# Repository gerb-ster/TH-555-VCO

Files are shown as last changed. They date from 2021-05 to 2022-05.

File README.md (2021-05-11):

# Thomas Henry 555 VCO

The famous VCO module by Thomas Henry based on the 555 timer IC. This was the first module I ever designed a PCB for, which, in hindsight, was not the smartest move. It took me quit a while to get it bug-free, but now that it works, I love it! Over the years I read a lot of articles and booklets by Thomas Henry and if you’re into this synth diy stuff, I highly recommend checking out him and his work. If you want to build/buy one yourself, there is also an excellent version out there by a guy named Fonitronik, there is a link below.

## Status: Finished

- done: first schematic & board design
- done: breadboard and test
- done: design frontpanel
- done: order PCB and build prototype

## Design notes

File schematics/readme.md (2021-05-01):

## Disclaimer

The files/schematics found in this folder are made with Eagle CAD v9.6.2.

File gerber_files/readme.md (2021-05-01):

## Gerber Files

This folder contains all Gerber files.

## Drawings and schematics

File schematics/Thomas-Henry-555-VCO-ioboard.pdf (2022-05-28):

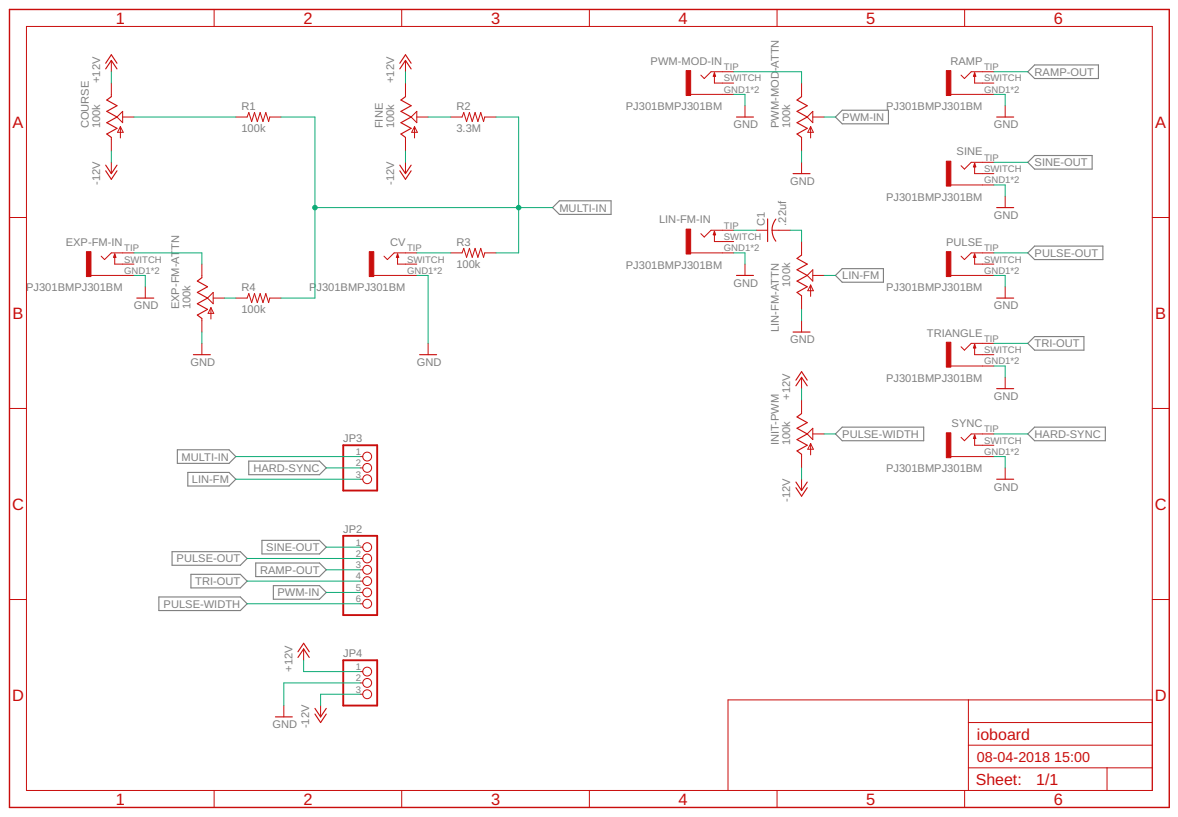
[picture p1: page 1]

SWITCH GND1*2 PWM-MOD-IN

SWITCH GND1*2 LIN-FM-IN

SWITCH GND1*2 EXP-FM-IN

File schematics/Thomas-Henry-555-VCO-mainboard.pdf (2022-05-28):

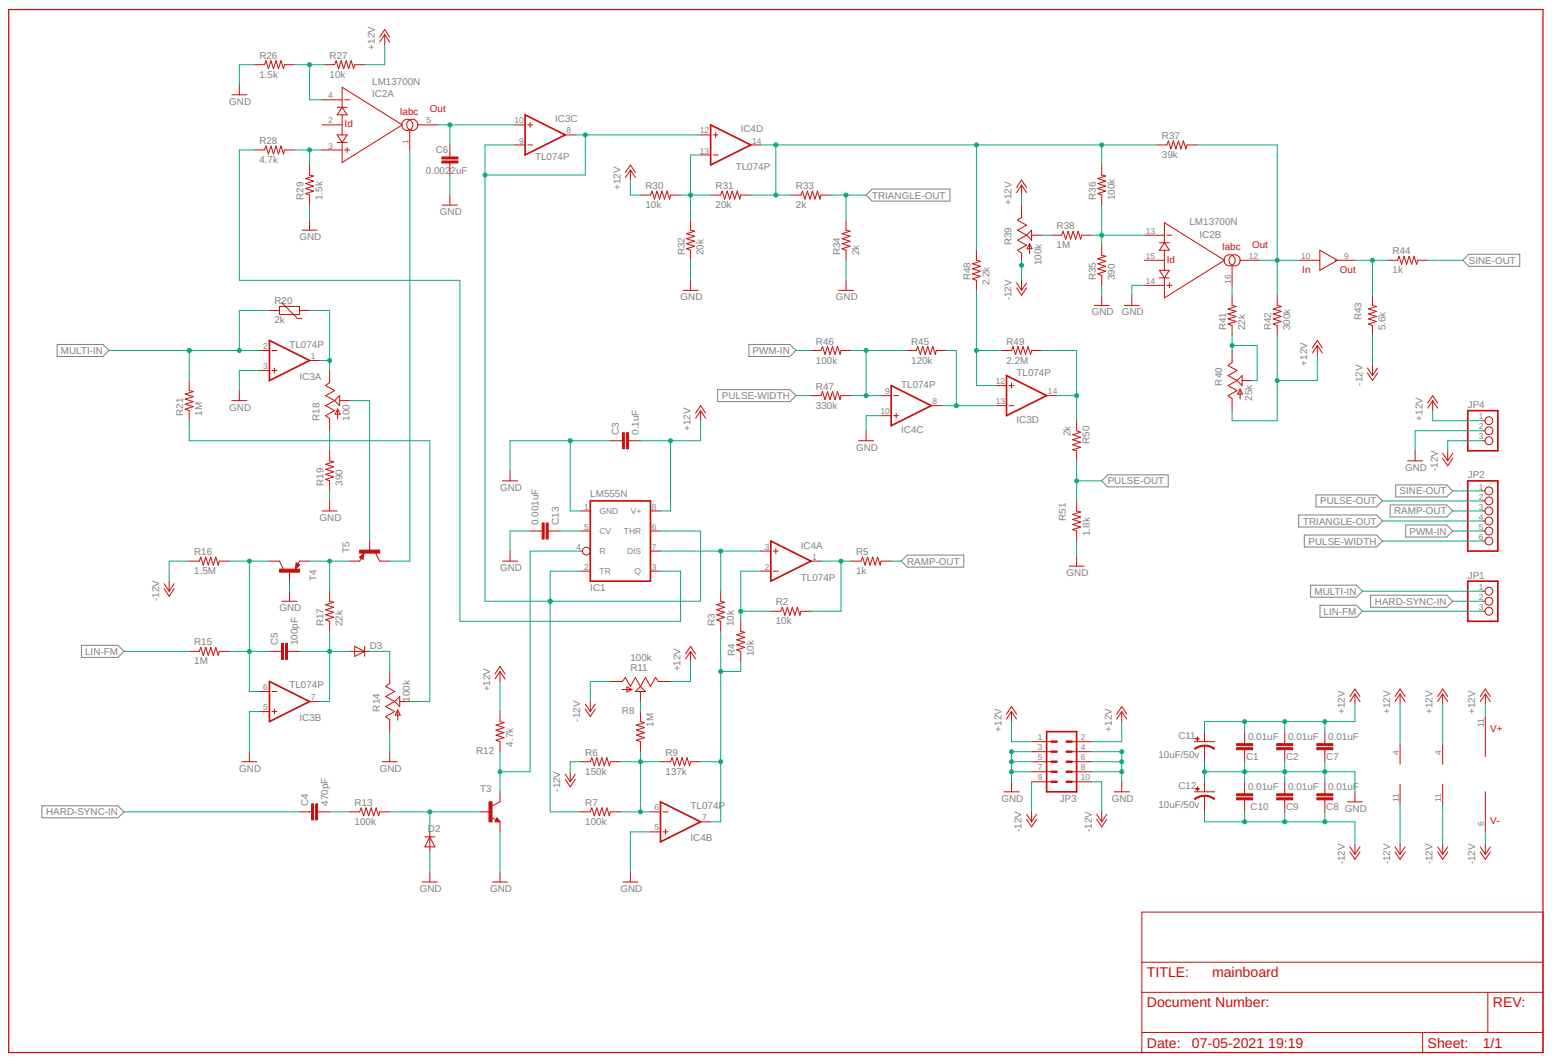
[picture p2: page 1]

Document Number: | REV:

Date: 07-05-2021 19:19 | Sheet: 1/1

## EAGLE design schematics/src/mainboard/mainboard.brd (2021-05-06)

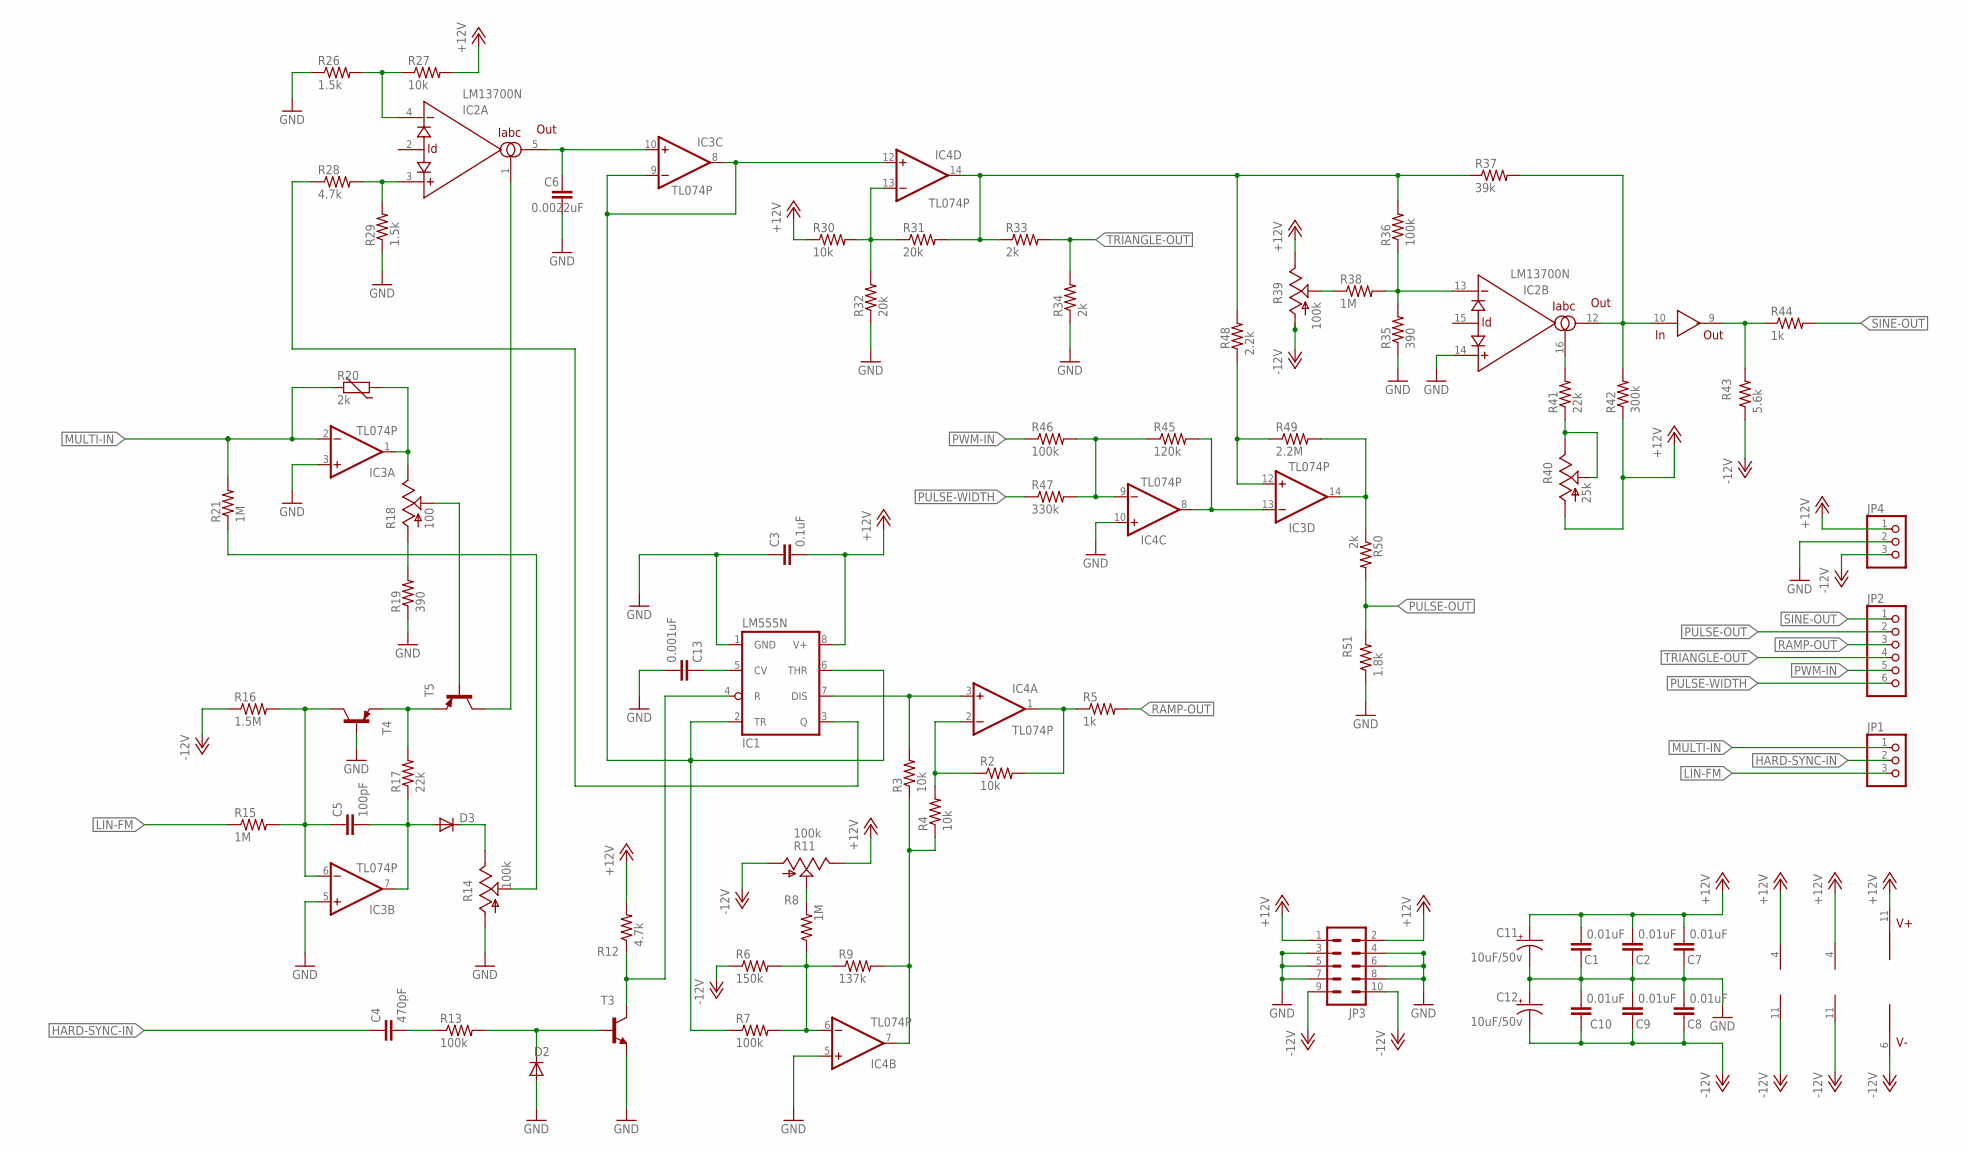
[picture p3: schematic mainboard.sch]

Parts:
C1, C2, C7, C8, C9, C10: 0.01uF; C050-024X044
C3: 0.1uF; C050-024X044
C4: 470pF; C050-024X044
C5: 100pF; C050-024X044
C6: 0.0022uF; C050-025X075
C11, C12: 10uF/50v; E2,5-6
C13: 0.001uF; C050-024X044
D2, D3: 1N4148DO35-7; DO35-7
IC1: LM555N; DIL08
IC2: LM13700N; DIL16
IC3, IC4: TL074P; DIL14
JP1, JP4: PINHD-1X3; 1X03
JP2: PINHD-1X6; 1X06
JP3: ML10
R2, R3, R4, R27, R30: 10k; 0204/7
R5, R44: 1k; 0204/7
R6: 150k; 0204/7
R7, R13, R36, R46: 100k; 0204/7
R8, R15, R21, R38: 1M; 0204/7
R9: 137k; 0204/7
R11, R14, R39: 100k; RJ9W
R12, R28: 4.7k; 0204/7
R16: 1.5M; 0204/7
R17, R41: 22k; 0204/7
R18: 100; RJ9W
R19, R35: 390; 0204/7
R20: 2k; R-5
R26, R29: 1.5k; 0204/7
R31, R32: 20k; 0204/7
R33, R34, R50: 2k; 0204/7
R37: 39k; 0204/7
R40: 25k; RJ9W
R42: 300k; 0204/7
R43: 5.6k; 0204/7
R45: 120k; 0204/7
R47: 330k; 0204/7
R48: 2.2k; 0204/7
R49: 2.2M; 0204/7
R51: 1.8k; 0204/7
T3: 2N3904-NPN-TO92-EBC; TO92-EBC
T4, T5: 2N3906-PNP-TO92-EBC; TO92-EBC

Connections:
+12V: C1.2, C2.2, C3.2, C7.2, C11.+, IC1.8 (V+), IC2.11 (V+), IC3.4 (V+), IC4.4 (V+), JP3.1, JP3.2, JP4.1, R11.E, R12.2, R27.2, R30.1, R39.E, R40.A, R42.1
-12V: C8.1, C9.1, C10.1, C12.-, IC2.6 (V-), IC3.11 (V-), IC4.11 (V-), JP3.9, JP3.10, JP4.3, R6.1, R11.A, R16.1, R39.A, R43.1
GND: C1.1, C2.1, C3.1, C6.2, C7.1, C8.2, C9.2, C10.2, C11.-, C12.+, C13.1, D2.A, IC1.1 (GND), IC2.14 (+IN), IC3.3 (+IN), IC3.5 (+IN), IC4.5 (+IN), IC4.10 (+IN), JP3.3, JP3.4, JP3.5, JP3.6, JP3.7, JP3.8, JP4.2, R14.A, R19.1, R26.1, R29.1, R32.1, R34.1, R35.1, R51.1, T3.E, T4.B
HARD-SYNC-IN: C4.1, JP1.2
LIN-FM: JP1.3, R15.1
MULTI-IN: IC3.2 (-IN), JP1.1, R20.2, R21.2
unnamed: IC1.7 (DIS), IC4.3 (+IN), R3.2
unnamed: IC4.2 (-IN), R2.1, R4.2
unnamed: IC4.1 (OUT), R2.2, R5.1
unnamed: IC4.7 (OUT), R3.1, R4.1, R9.2
unnamed: IC4.6 (-IN), R6.2, R7.2, R8.1, R9.1
unnamed: R38.1, R39.S
unnamed: C5.1, IC3.6 (-IN), R15.2, R16.2, T4.C
unnamed: R8.2, R11.S
unnamed: C5.2, D3.A, IC3.7 (OUT), R17.1
unnamed: C4.2, R13.1
unnamed: D2.C, R13.2, T3.B
unnamed: IC1.4 (R), R12.1, T3.C
unnamed: R17.2, T4.E, T5.E
unnamed: D3.C, R14.E
unnamed: R14.S, R21.1
unnamed: IC3.1 (OUT), R18.E, R20.1
unnamed: R18.S, T5.B
unnamed: IC2.1 (IABC), T5.C
unnamed: R18.A, R19.2
unnamed: IC2.3 (+IN), R28.2, R29.2
unnamed: IC1.3 (Q), R28.1
unnamed: IC2.4 (-IN), R26.2, R27.1
unnamed: C6.1, IC2.5 (OUT), IC3.10 (+IN)
unnamed: IC1.2 (TR), IC1.6 (THR), IC3.8 (OUT), IC3.9 (-IN), IC4.12 (+IN), R7.1
unnamed: IC4.13 (-IN), R30.2, R31.1, R32.2
unnamed: IC2.13 (-IN), R35.2, R36.1, R38.2
unnamed: IC4.14 (OUT), R31.2, R33.1, R36.2, R37.1, R48.2
unnamed: IC2.16 (IABC), R41.2
unnamed: R40.E, R40.S, R41.1
unnamed: IC2.10 (IN), IC2.12 (OUT), R37.2, R42.2
unnamed: IC2.9 (OUT), R43.2, R44.1
unnamed: IC3.13 (-IN), IC4.8 (OUT), R45.2
unnamed: C13.2, IC1.5 (CV)
unnamed: IC4.9 (-IN), R45.1, R46.2, R47.2
unnamed: IC3.12 (+IN), R48.1, R49.1
unnamed: IC3.14 (OUT), R49.2, R50.1
PULSE-OUT: JP2.2, R50.2, R51.2
PULSE-WIDTH: JP2.6, R47.1
PWM-IN: JP2.5, R46.1
RAMP-OUT: JP2.3, R5.2
SINE-OUT: JP2.1, R44.2
TRIANGLE-OUT: JP2.4, R33.2, R34.2

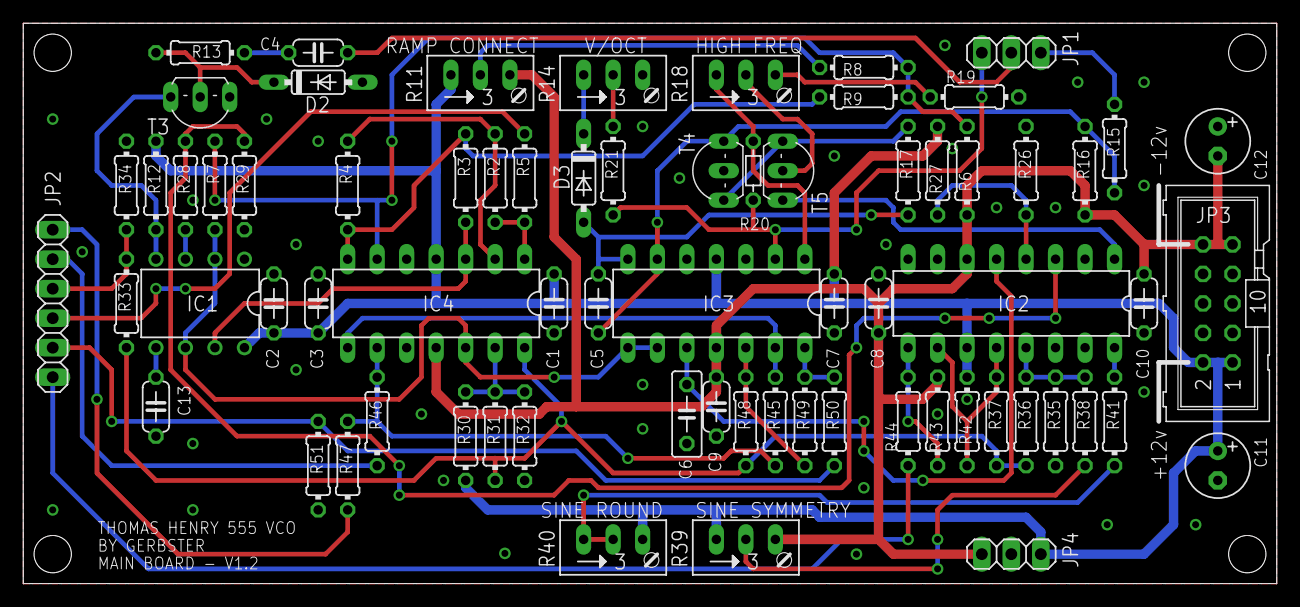
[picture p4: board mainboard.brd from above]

Board: 2 copper layers, 108.0 x 48.3 mm, 71 parts (0 on the bottom side), 48 nets.

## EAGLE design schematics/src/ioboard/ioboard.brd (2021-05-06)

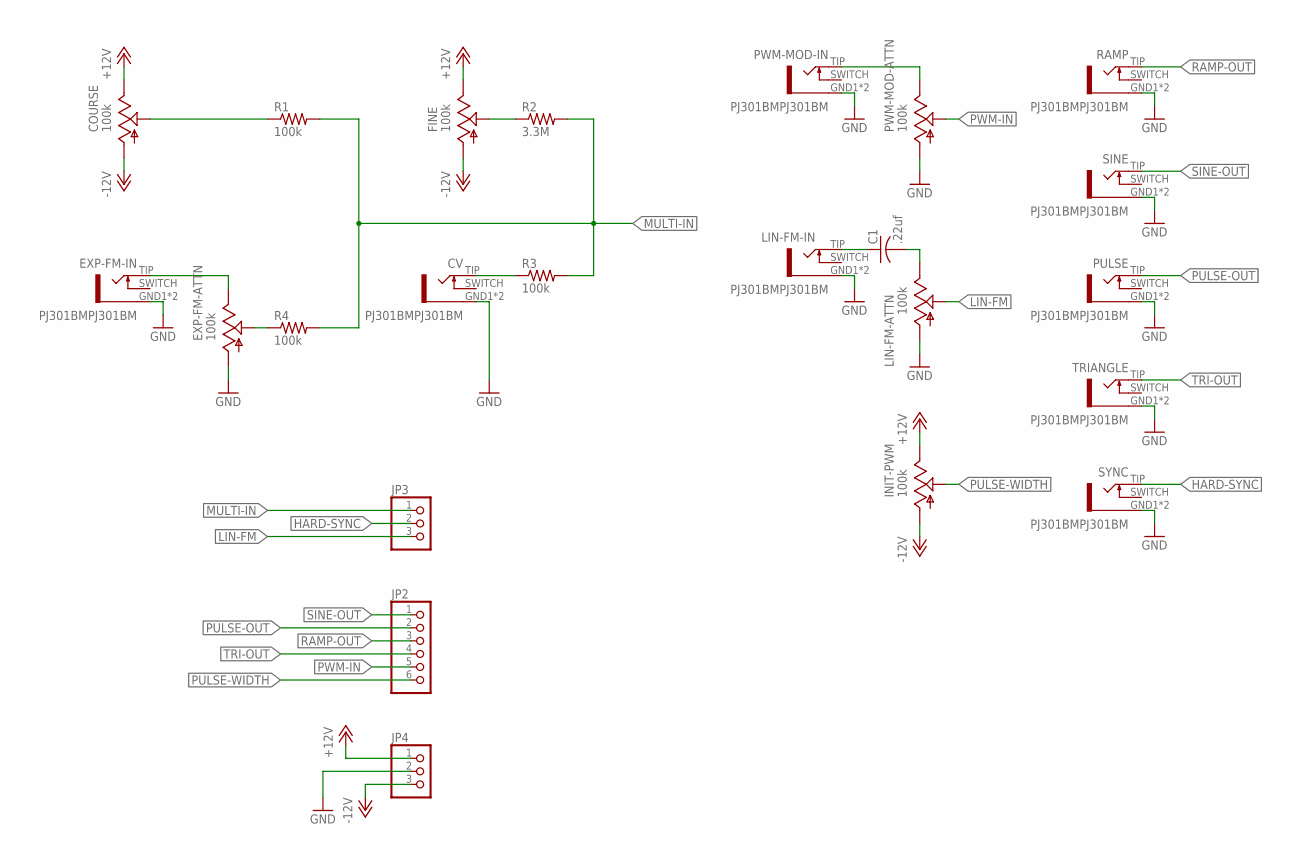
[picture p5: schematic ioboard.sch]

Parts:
C1: .22uf; C050-024X044
COURSE: 100k; EVUF
CV: PJ301BMPJ301BM; PJ301BM
EXP-FM-ATTN: 100k; EVUF
EXP-FM-IN: PJ301BMPJ301BM; PJ301BM
FINE: 100k; EVUF
INIT-PWM: 100k; EVUF
JP2: PINHD-1X6; 1X06
JP3, JP4: PINHD-1X3; 1X03
LIN-FM-ATTN: 100k; EVUF
LIN-FM-IN: PJ301BMPJ301BM; PJ301BM
PULSE: PJ301BMPJ301BM; PJ301BM
PWM-MOD-ATTN: 100k; EVUF
PWM-MOD-IN: PJ301BMPJ301BM; PJ301BM
R1, R3, R4: 100k; 0207/10
R2: 3.3M; 0207/10
RAMP: PJ301BMPJ301BM; PJ301BM
SINE: PJ301BMPJ301BM; PJ301BM
SYNC: PJ301BMPJ301BM; PJ301BM
TRIANGLE: PJ301BMPJ301BM; PJ301BM

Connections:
1V/OCT: CV.TIP (3), R3.1
+12V: COURSE.3 (E), FINE.3 (E), INIT-PWM.3 (E), JP4.1
-12V: COURSE.1 (A), FINE.1 (A), INIT-PWM.1 (A), JP4.3
COARSE: COURSE.2 (S), R1.1
EXP-FM: EXP-FM-ATTN.3 (E), EXP-FM-IN.TIP (3)
EXP-FM-ATTN: EXP-FM-ATTN.2 (S), R4.1
FINE: FINE.2 (S), R2.1
GND: CV.GND1 (5), CV.GND2 (5), EXP-FM-ATTN.1 (A), EXP-FM-IN.GND1 (5), EXP-FM-IN.GND2 (5), JP4.2, LIN-FM-ATTN.1 (A), LIN-FM-IN.GND1 (5), LIN-FM-IN.GND2 (5), PULSE.GND1 (5), PULSE.GND2 (5), PWM-MOD-ATTN.1 (A), PWM-MOD-IN.GND1 (5), PWM-MOD-IN.GND2 (5), RAMP.GND1 (5), RAMP.GND2 (5), SINE.GND1 (5), SINE.GND2 (5), SYNC.GND1 (5), SYNC.GND2 (5), TRIANGLE.GND1 (5), TRIANGLE.GND2 (5)
HARD-SYNC: JP3.2, SYNC.TIP (3)
LIN-FM: JP3.3, LIN-FM-ATTN.2 (S)
MULTI-IN: JP3.1, R1.2, R2.2, R3.2, R4.2
unnamed: PWM-MOD-ATTN.3 (E), PWM-MOD-IN.TIP (3)
unnamed: C1.2, LIN-FM-ATTN.3 (E)
unnamed: C1.1, LIN-FM-IN.TIP (3)
PULSE-OUT: JP2.2, PULSE.TIP (3)
PULSE-WIDTH: INIT-PWM.2 (S), JP2.6
PWM-IN: JP2.5, PWM-MOD-ATTN.2 (S)
RAMP-OUT: JP2.3, RAMP.TIP (3)
SINE-OUT: JP2.1, SINE.TIP (3)
TRI-OUT: JP2.4, TRIANGLE.TIP (3)

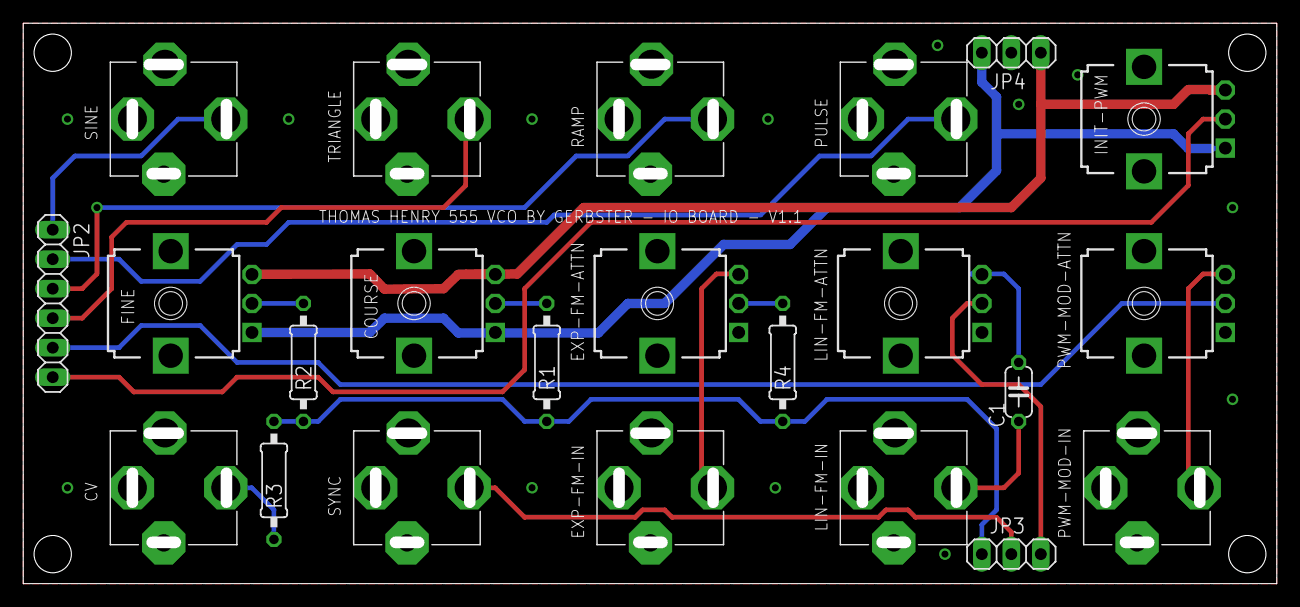
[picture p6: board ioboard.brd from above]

Board: 2 copper layers, 108.0 x 48.3 mm, 23 parts (0 on the bottom side), 20 nets.

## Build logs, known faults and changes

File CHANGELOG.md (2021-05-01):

# Changelog

All notable changes to this project will be documented in this file.

The format is based on [Keep a Changelog](https://keepachangelog.com/en/1.0.0/),
and this project adheres to [Semantic Versioning](https://semver.org/spec/v2.0.0.html).

## [1.0.0] - 2021-01-05

### Added

- Inintial repo setup

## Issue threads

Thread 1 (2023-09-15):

PSU connector reversed

Biondilbiondo, 2023-09-15:
Hi, the PSU connector is reversed wrt the eurorack standard. Pin 1 should be -12 V and pin 10 +12 V (https://division-6.com/learn/eurorack-power/ and https://doepfer.de/a100_man/a100t_e.htm).
In your schematic and on your website (https://www.gerbster.nl/wp-content/uploads/2021/02/IMG_2688-scaled.jpeg) it seems that pin 1 should be +12 V and pin 10 -12 V. This is easily worked around by mounting the connector with the hole looking at the interior of the PCB, so in the opposite way respect to what is marked on the silkscreen.
I was extremely cautious, and I double-checked everything before connecting to the PSU but someone can burn all the chips and explode the two electrolytic capacitors due to this error. Please state this clearly and loud in the readme.md !

kristjem, 2024-11-20:
@Biondilbiondo have you successfully built this module, and does it work as expected if you rotate the 10 pin header connector 180 degrees? I'm considering ordering PCBs.

Biondilbiondo, 2024-11-20:
Yes it works with the connector reversed. If you are interested in the module write me, I have some spare PCBs which I'm happy to send you to avoid to waste them...

kristjem, 2024-11-20:
> Yes it works with the connector reversed. If you are interested in the module write me, I have some spare PCBs which I'm happy to send you to avoid to waste them...

Brilliant! Thanks, I've sent you an email.

AuguB, 2024-12-24:
Hi @Biondilbiondo , do you happen to have some more space pcb's? Otherwise I will place an order myself.

gerb-ster, 2024-12-24:
I think so, drop me an email at gerb@gerbster.nl and I'll let you know!

Biondilbiondo, 2024-12-25:
I do have a last set of PCBs, if you need it, I can send you for free. In case you're interested, just write me.

8lall0, 2025-01-03:
Hi @Biondilbiondo , i'll be interested too!

Biondilbiondo, 2025-01-05:
My spear parts are over sorry.

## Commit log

2021-05-06 some files
    [TH555-IO.brd, TH555-IO.sch, TH555-MainBoard.brd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]
2021-05-07 Added files & structure
    [Thomas-Henry-555-VCO-ioboard.GBL, Thomas-Henry-555-VCO-ioboard.GBO, Thomas-Henry-555-VCO-ioboard.GBP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]
2021-08-06 Updated some schematics and docs
    [Thomas-Henry-555-VCO-ioboard.GBL, Thomas-Henry-555-VCO-ioboard.GBO, Thomas-Henry-555-VCO-ioboard.GBP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]
2021-08-10 Fixed some bugs and updated documentation
    [Thomas-Henry-555-VCO-ioboard.XLN, Thomas-Henry-555-VCO-mainboard.XLN, gerber_job.gbrjob]
2022-04-20 Some updates & bugfixes
    [Thomas-Henry-555-VCO-ioboard.XLN, Thomas-Henry-555-VCO-mainboard.XLN, gerber_job.gbrjob]
2022-04-22 Fixed schematics & descriptions
    [Thomas-Henry-555-VCO-ioboard.XLN, Thomas-Henry-555-VCO-mainboard.XLN, gerber_job.gbrjob]
2022-05-17 Updated Firmware
    [Thomas-Henry-555-VCO-ioboard.XLN, Thomas-Henry-555-VCO-mainboard.XLN, gerber_job.gbrjob]
2022-05-18 Updated Faceplates
    [Thomas-Henry-555-VCO-ioboard.XLN, Thomas-Henry-555-VCO-mainboard.XLN, gerber_job.gbrjob]
2022-05-18 Fixed issues
    [Thomas-Henry-555-VCO-ioboard.XLN, Thomas-Henry-555-VCO-mainboard.XLN, gerber_job.gbrjob]
2022-05-21 Fixed schematics
    [Thomas-Henry-555-VCO-ioboard.XLN, Thomas-Henry-555-VCO-mainboard.XLN, gerber_job.gbrjob]
2022-05-28 General updates
    [Thomas-Henry-555-VCO-ioboard.GKO, Thomas-Henry-555-VCO-mainboard.GKO, copper_bottom.gbr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]
